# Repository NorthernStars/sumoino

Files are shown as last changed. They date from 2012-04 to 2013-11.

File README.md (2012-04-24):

Sumorobot library for Arduino
=============================

DESCRIPTION:
------------

* this library can be used to control 2 servo motors and 2 distance + 3 light sensors
* in the project you can also find the schematics for the arduino extensionboard

1) copy Sumorobot into your arduino libraries folder
2) restart Arduino and press Sketch > Import Library... > Sumorobot
3) check out the documentation "Sumorobot2012_documentation.pdf"
4) write some code xD (also the examples "Drive_EN", "Avoid_EN", "Opponent_EN" are available)

# download the library to the tmp and copy the library to the installed arduino
cd /var/tmp
git clone http://github.com/silps/sumoino.git
sudo cp -R sumoino/Sumorobot /usr/share/arduino/libraries

# if you don't have arduino 1.0 you need to do this additional step
# this will rename the example file formats into the old arduino format
sudo for i in `find /usr/share/arduino/libraries/Sumorobot/examples -name *.ino`;do mv $i ${i%.*}.pde;done

# after everything is done, open arduino and enjoy xD

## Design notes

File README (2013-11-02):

DESCRIPTION
===========

* this Arduino Sumorobot platform is developed for beginner programmers
* this Sumorobot uses 2 servo motors and 2 distance + 3 light sensors
* schematics folder contains the Arduino shield schematics
* frame folder containts the schematics for the frame
* documentation folder contains the documents for a Sumorobot workshop

INSTALLATION
============

Steps:
1) copy Sumorobot into your arduino libraries folder and restart arduino
2) check out the documentation https://github.com/silps/sumoino/raw/master/documentation/student.pdf
3) write some code xD (tip: see examples "Drive_EN", "Avoid_EN", "Opponent_EN")

Commands:
# this will install latest arduino and the Sumorobot library
# make sure that you will get arduino 1.0
sudo apt-get update && sudo apt-get install arduino && arduino
cd /var/tmp && git clone http://github.com/silps/sumoino.git
sudo cp -R sumoino/Sumorobot /usr/share/arduino/libraries

OTHER LINKS
===========
The gallery on google+ https://plus.google.com/photos/118227730440670321584/albums/5777266184562058609
The guide on instructables http://www.instructables.com/id/Arduino-Sumorobot/
The project poster https://www.sharelatex.com/project/52598a10e0deb8d1340053ea
The workshop slides https://docs.google.com/presentation/d/194JcJHCedPZimk41OGD4uriet_0rB0_b3bzhDWw4v1Q
The project report https://www.sharelatex.com/project/526d74ac7eea94a263004071

CREDITS ^-^
===========

* EIK Robotics Group
* NorthernStars Robotics Group
* Arduino developers
* Android developers
* Phonegap developers
* Blockly developers
* Amarino developers
* avrdude developers

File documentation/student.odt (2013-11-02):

# Sumoroboti programmeerimise juhend

### Liikumine

viivitus(1000); | Eelnevat käsku täidetakse 1000 millisekundit
stopp(); | Robot jääb seisma
edasi(); | Robot sõidab otse edasi
tagasi(); | Robot sõidab tagurpidi
paremale(); | Robot sõidab paremale
vasakule(); | Robot sõidab vasakule

### Edasijõudnutele

viivitus(SEKUND/2); | Eelnevat käsku täidetakse pool sekundit (Vihje: võib ka kasutada SEKUND/4 või teisi väärtusi)
paremMootor(suund, kiirus); Näide: paremMootor(EDASI, 75); | Roboti parema mootori kiiruse seadmine. Tuleb määrata suund ja kiirus (protsentides): suund > EDASI või TAGASI kiirus > 0 kuni 100
vasakMootor(suund, kiirus); Näide: vasakMootor(TAGASI, 50); | Roboti vasaku mootori kiiruse seadmine. Tuleb määrata suund ja kiirus (protsentides): suund > EDASI või TAGASI kiirus > 0 kuni 100

### Vastane

VASTANE_PAREM | Robot näeb vastast parema anduriga
VASTANE_VASAK | Robot näeb vastast vasaku anduriga
VASTANE_EES | Robot näeb vastast nii vasaku kui ka parema anduriga

### Joon

ALL_PAREM | Roboti all olev parempoolne joone andur
ALL_VASAK | Roboti all olev vasakpoolne joone andur
ALL_KESKMINE | Roboti all olev keskmine joone andur

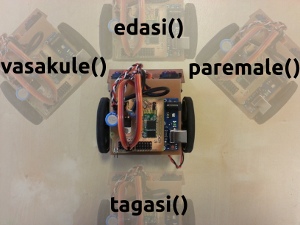
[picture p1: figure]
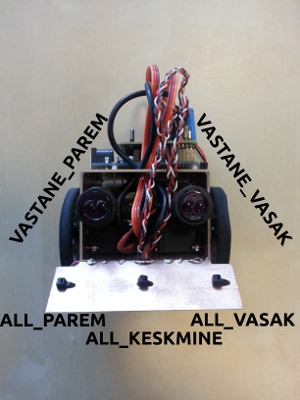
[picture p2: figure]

### Programmeerimine

Programmi struktuur

Sumoroboti programmeerimiseks kasutame järgnevat Arduino programmi struktuuri:

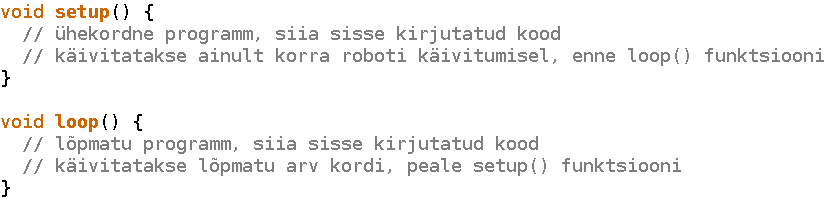
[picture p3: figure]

Vajalike teekide lisamine

Sumoroboti juhtimiseks lisa Sumoroboti ja Servo teegid, mis sisaldavad vajalikke funktsioone, et sumorobotit juhtida. Selleks vajuta arduino keskkonnas järgnevaid nuppe menüüst:
1) 2) 3)

4) 5) 6)

Programmi kompileerimine ja laadimine

Kui programm on valmis, siis vajuta nuppu menüüst, et see kompileerida. Veendu, et näed vasakul all nurgas teadet. Viimaks vajuta, et programm Sumorobotisse laadida.

Juhul, kui Arduino leidis programmis vigu, annab ta veateate . Sellel juhul kontrolli oma kood üle ning raskuste korral kutsu appi juhendaja.

Näiteprogrammid

Kahtluse korral saab ka proovida näiteprogramme, need leiab järgnevate menüü nupuvajutustega:

1) 2) 3)

Sealt tuleb valida sobiv näide EE lõpuga.

Lõbusat programmeerimist!

# Sumorobot programming guide

### Movement

delay(1000); | Previous command is carried out for 1000 milliseconds
stop(); | The robot stops
forward(); | The robot moves forward
backward(); | The robot moves backwards
right(); | The robot moves right
left(); | The robot moves left

### Advanced

delay(SECOND/2); | Previous command is carried out for half a second (Tip: SECOND/4 or other values may also be used)
rightMotor(direction, speed); Example: rightMotor(FORWARD, 75); | To set the speed of the right motor. Specify the direction and speed (in percentage): direction > FORWARD or BACKWARD speed > 0 to 100
leftMotor(direction, speed); Example: leftMotor(BACKWARD, 50); | To set the speed of the left motor. Specify the direction and speed (in percentage): direction > FORWARD or BACKWARD speed > 0 to 100

### Opponent

OPPONENT_RIGHT | The robot sees the opponent with the right sensor
OPPONENT_LEFT | The robot sees the opponent with the left sensor
OPPONENT_FRONT | The robot sees the opponent with both the left and right sensor

### Line

BOTTOM_RIGHT | The right line sensor under the robot
BOTTOM_LEFT | The left line sensor under the robot
BOTTOM_MIDDLE | The middle line sensor under the robot

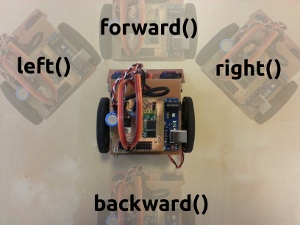
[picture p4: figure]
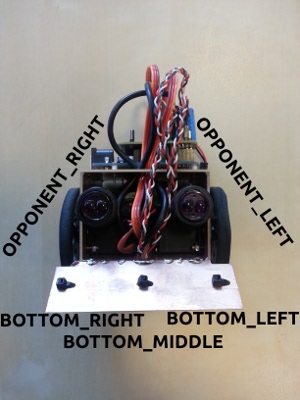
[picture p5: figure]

### Programming

Program structure

The following Arduino program structure is used to program the Sumorobot:

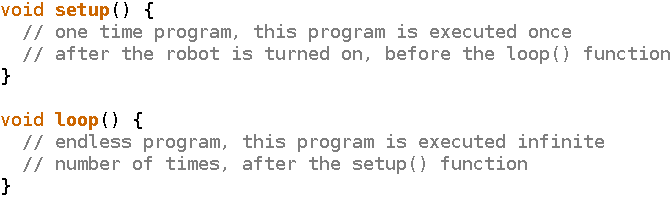
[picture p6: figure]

Adding necessary libraries

For controlling the Sumorobot we need to add the Sumorobot and Servo library, which contain necessary functions to control the Sumorobot. For that click on the following menu buttons:
1) 2) 3)

4) 5) 6)

Compiling and uploading

When the program is ready, then push from the menu, to compile the program. Be sure that you see the message on the bottom left corner. Finally press and the program will be uploaded.

In case Arduino found bugs in your program, you will see the message . In this case recheck your program and if in doubt ask the supervisor for help.

Example programs

There are also example programs available, if in doubt. They can be found by pressing the following menu buttons:

1) 2) 3)

From there you need to choose the examples ending with EN.

Happy programming!

# Anleitung für Sumorobot Programmierung

### Bewegung

warte(1000); | Letzter Befehl wird 1000 millisekunden ausgeführt
stop(); | Der Roboter hält an
vorwaerts(); | Der Roboter fährt vorwaerts
rueckwaerts(); | Der Roboter fährt rückwaerts
rechts(); | Der Roboter fährt nach rechts
links(); | Der Roboter fährt nach links

### Vortgeschritten

warte(SEKUNDE/2); | Letzter Befehl wird halbe Sekunde ausgeführt (Tip: SEKUNDE/4 oder auch andere Werte)
rechterMotor(richtung, geschwind.); Beispiel: rechterMotor(VORWAERTS, 75); | Um die Geschwindigkeit von dem linken Motor zu bestimmen. Gib die Richtung und Geschwindigkeit: richtung > VORWAERTS oder RUCKWERTS geschwindigkeit > 0 bis 100 (im Protzent)
linkerMotor(richtung, geschwind.); Beispiel: linkerMotor(RUECKWAERTS, 50); | Um die Geschwindigkeit von dem rechten Motor zu bestimmen. Gib die Richtung und Geschwindigkeit richtung > VORWAERTS oder RUECKWAERTS geschwindigkeit > 0 bis 100 (im Protzent)

### Gegner

GEGNER_RECHTS | Der rechter Gegner-Sensor auf dem Roboter (Gegner rechts)
GEGNER_LINKS | Der linke Gegner-Sensor auf dem Roboter (Gegner links)
GEGNER_VORNE | Beide Gegner-Sensoren auf dem Roboter (Gegner vorne)

### Linie

UNTEN_RECHTS | Der rechte Linien-Sensor (Linie rechts)
UNTEN_LINKS | Der linke Linien-Sensor (Linie links)
UNTEN_MITTE | Der mittlere Linien-Sensor (Linie vorne)

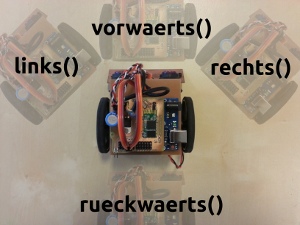
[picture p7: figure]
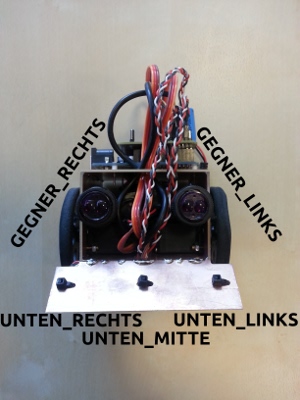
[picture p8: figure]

### Programmierung

Struktur vom Programm

Die folgende Arduino Programmstruktur wird benutzt um den Sumoroboter zu programmieren:

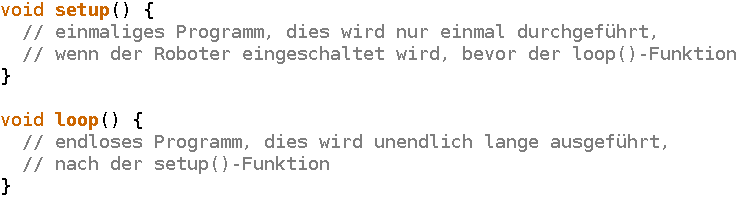
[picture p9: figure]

Benötigte Bibliotheken

Für die Kontrolle von dem Sumoroboter brauchen wir die Sumorobot und Servo Bibliothek. Am Menü wähle folgendes:
1) 2) 3)

4) 5) 6)

Kompilierung und Upload

Wenn der Programm fertig ist, dann drück , um es to kompilieren. Sei sicher, dass Du die Nachricht siehst. Am ende drücke um den Program zu uploaden.

Im Falle das Arduino Bugs gefunden hat wirst du die Nachricht sehen. Im diesem Falle überprüfe nochmal dein Porgramm und im Zweifel frage deinen Betruer.

Beispiel Programme

Im Zweifel gibt es auch Beispiel Programme. Die kann man im Menü folgender weise finden:

1) 2) 3)

Darunter muss man die Beispiele mit dem Ende DE auswählen.

Viel Spaß beim programmieren!

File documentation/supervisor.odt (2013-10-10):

# Sumoroboti töötoa ettevalmistamine

Enne igat koolitust tuleb veenduda, et:

1. Arvutitel on Arduino ja Sumoroboti teek installeeritud:
- lae alla ja installeeri Arduino http://www.arduino.cc/download
- lae alla ja installeeri Sumoroboti teek https://github.com/silps/sumoino
2. Sumoroboti akud oleks täidetud:
- multimeetriga mõõda ligikaudu 7,4V aku kohta
3. Sumorobotil töötavad näiteprogrammid:
- lae Sumorobotisse näiteprogramm

Juhul, kui midagi ei tööta:

Vaata üle kas juhtmed on õigesti ühendatud:

- parem mootor nr 6 ja vasak nr 5 pistikus
- vastase parem andur nr 0 ja vasak nr 1 pistikus
- joone parem andur nr 2, keskmine nr 3 ja vasak nr 4 pistikus

Kasuta teeki sisse ehitatud “test” funktsioone:

- testOpponent(); ( nähes vastast, ründab )
- testLine(); ( sõidab otse ja väldib joont )
- testSensors(); ( väljastab kõik anduri väärtused konsooli )

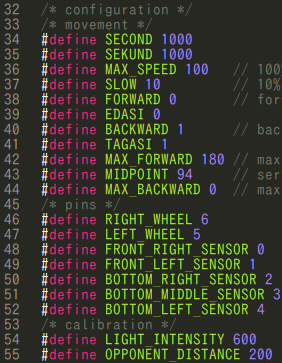
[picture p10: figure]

Kalibreeri võimalike väärtusi “Sumo.h” failis:

- valguse intensiivsust jooneanduril ( LIGHT_INTENSITY )
- vastase nägemise kaugust ( OPPONENT_DISTANCE )
- servo mootorite keskpunkti, ehk stopp punkti ( MIDPOINT )

# Sumorobot Workshop preparation

Before the workshop, be sure that:

1. The computers have Arduino and the Sumorobot library installed:
- download and install Arduino http://www.arduino.cc/download
- download and install the Sumoroboti library https://github.com/silps/sumoino
2. The batteries of the Sumorobots are charged:
- measure approximately 7,4V per battery
3. The example programs are working on the Sumorobots:
- upload the examples to the Sumorobots

In case something doesn't work:

Check that all cables are connected correctly:

- right motor nr 6 and left nr 5 pin
- opponent right sensor nr 0 and left nr 1 pin
- line right sensor nr 2, middle nr 3 and left nr 4 pin

Use the built-in “test” functions:

- testOpponent(); ( attacks the opponent, when in range )
- testLine(); ( drives forward and avoids line )
- testSensors(); ( prints out all the sensor values to the console )

Calibrate possible values in “Sumo.h” file:

- the light intensity of the line sensor ( LIGHT_INTENSITY )
- the opponent detection distance ( OPPONENT_DISTANCE )
- servo motor midpoint or stopping point ( MIDPOINT )

# Sumoroboter Workshop Vorbereitung

Vor dem Workshop, sei sicher dass:

1. Die Computer haben Arduino und die Sumoroboter Bibliothek installiert:
- downloade und installiere Arduino http://www.arduino.cc/download
- downloade und installiere die Bibliothek https://github.com/silps/sumoino
2. Die Batterien von den Sumorobotern sind voll:
- messe ungefähr 7,4V pro Batterie
3. Die Beispiel Programme funktionieren auf den Sumorobotern:
- uploade die Beispiele auf die Sumoroboter

Im Falle das was nicht funktsioniert:

Siehe ob alle Kabel richting verbunden sind:

- rechter Motor nr 6 und linker nr 5 pin
- rechter Gegner-Sensor nr 0 und linker nr 1 pin
- rechter Linien-Sensor nr 2, mitlerer nr 3 und linker nr 4 pin

Benutze die built-in “test” Funktione:

- testOpponent(); ( greift den Gegner an, wenn im Umfeld )
- testLine(); ( fährt vorwaerts und vermeidet die Linie )
- testSensors(); ( schick alle Sensor Daten in die Konsole )

Kalibriere mögliche Werte in File “Sumo.h”:

- die Intensität vom Lichtsensor ( LIGHT_INTENSITY )
- die Gegnererkennungs-Distanz ( OPPONENT_DISTANCE )
- der Mittelwert oder Stoppwert vom Servo ( MIDPOINT )

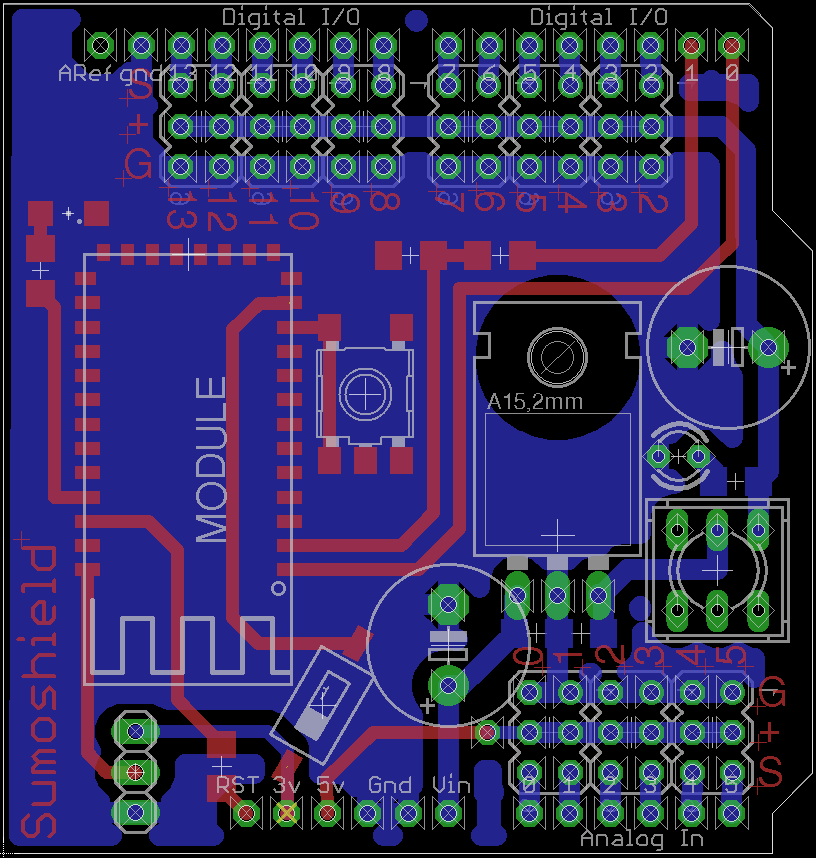
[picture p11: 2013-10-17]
schematics/board.png

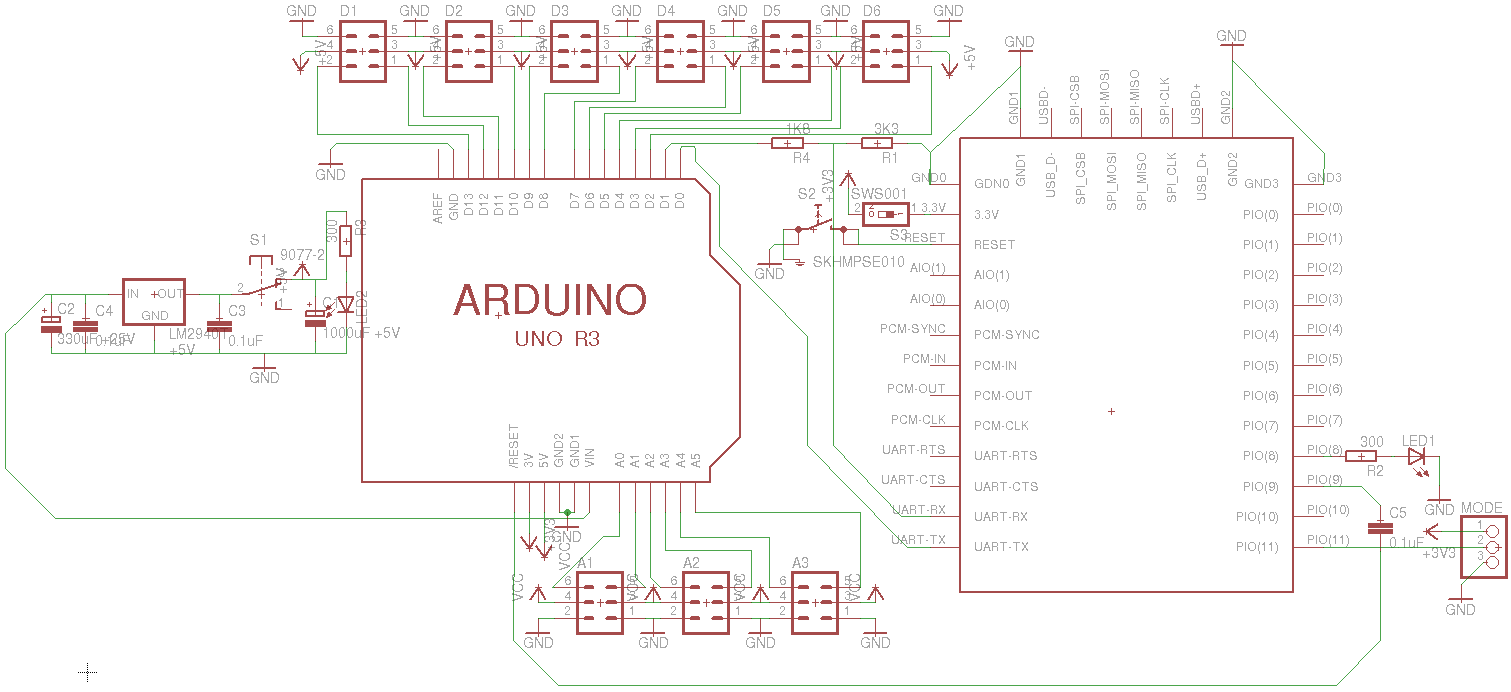
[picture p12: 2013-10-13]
schematics/schema.png

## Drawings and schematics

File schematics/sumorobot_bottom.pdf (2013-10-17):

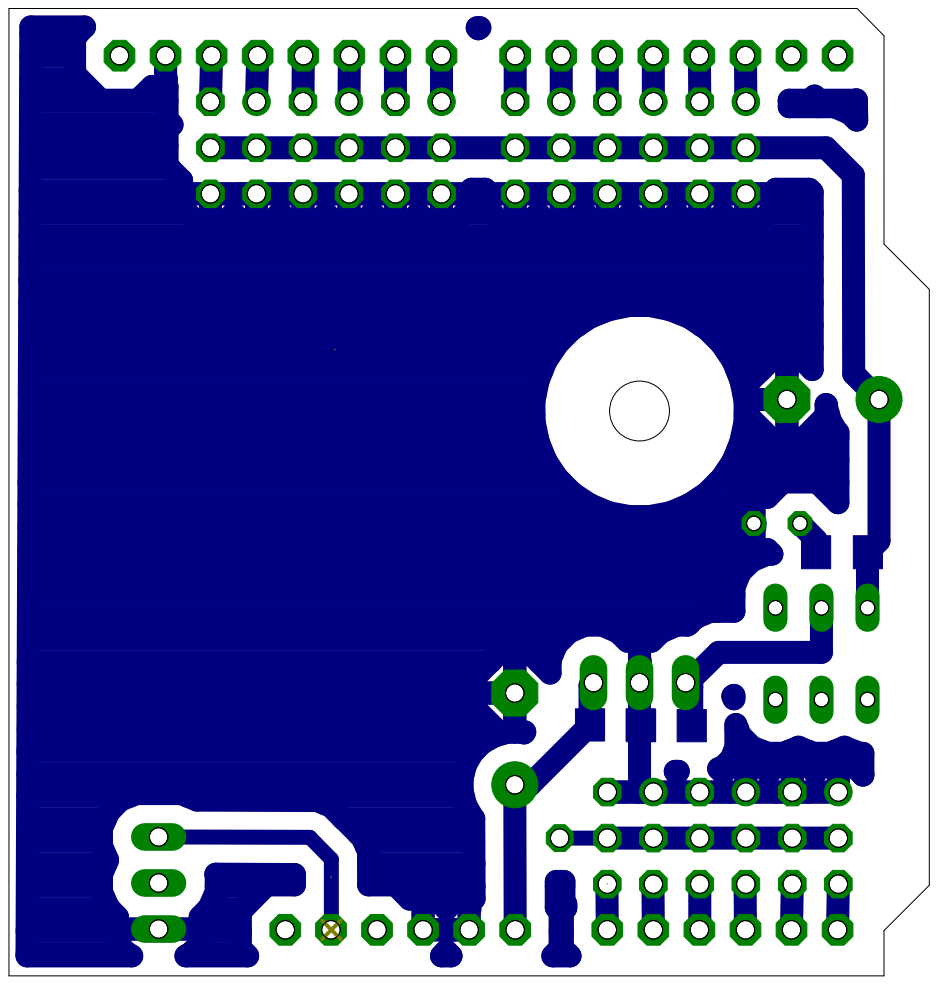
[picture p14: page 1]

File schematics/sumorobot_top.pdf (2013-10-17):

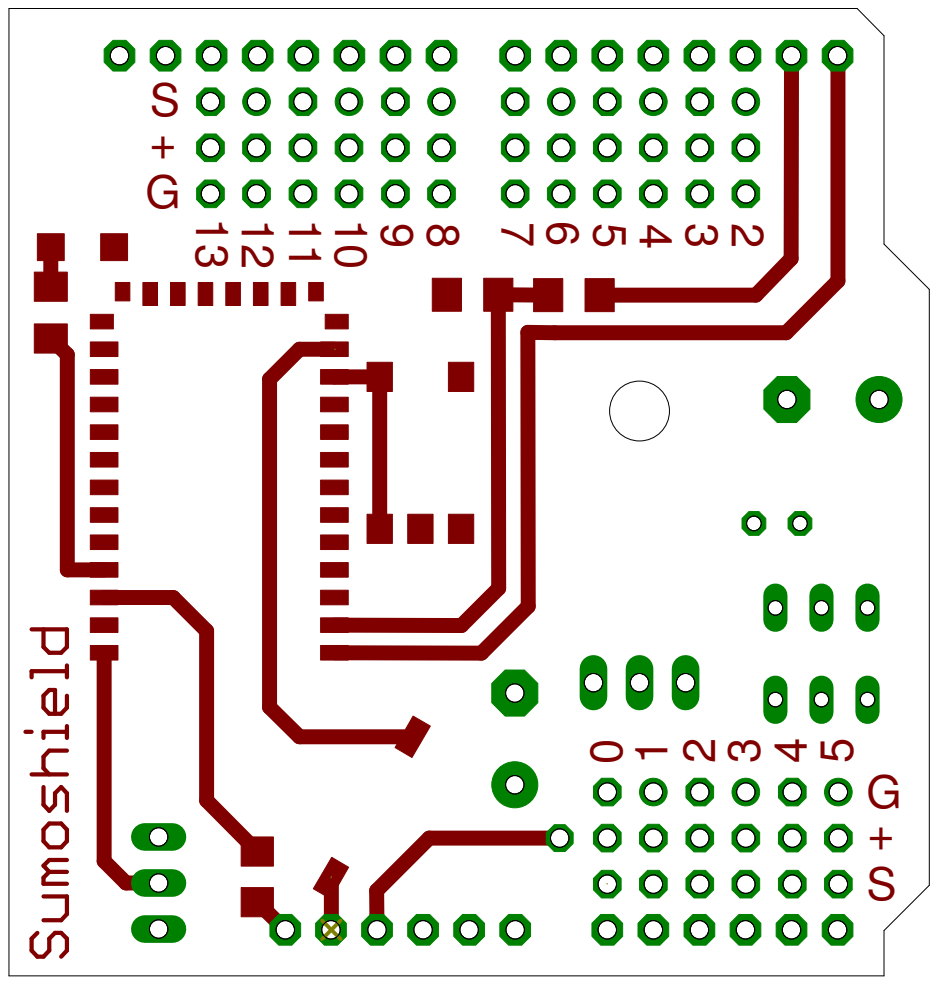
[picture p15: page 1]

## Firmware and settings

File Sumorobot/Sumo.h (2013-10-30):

/*
Sumo.h - Sumorobot library for Arduino

Author (C) 2012 The Estonian Information Technology College Robotics Club
Author (C) 2012 Silver Kuusik <silver.kuusik@gmail.com>

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
You should have received a copy of the GNU General Public License
along with this program; if not, write to the Free Software
Foundation, Inc., 51 Franklin Street, Fifth Floor, Boston, MA  02110-1301, USA.
*/

#ifndef Sumo_h
#define Sumo_h

#include "../Servo/Servo.h"

/* for C style compilation */
extern "C" {
  #include "stdlib.h"
}

/* configuration */
/* movement */
#define MAX_FORWARD 180 // max forward speed
#define MIDPOINT 90     // servo midpoint, brake
#define MAX_BACKWARD 0  // max backward speed
/* pins */
#define RIGHT_WHEEL 6
#define LEFT_WHEEL 5
#define FRONT_RIGHT_SENSOR 0
#define FRONT_LEFT_SENSOR 1
#define BOTTOM_RIGHT_SENSOR 2
#define BOTTOM_MIDDLE_SENSOR 3
#define BOTTOM_LEFT_SENSOR 4
/* calibration */
#define LIGHT_INTENSITY 600
#define OPPONENT_DISTANCE 200
/* for further calibration */
#define OPPONENT_DISTANCE_LEFT OPPONENT_DISTANCE
#define OPPONENT_DISTANCE_RIGHT OPPONENT_DISTANCE
#define LIGHT_INTENSITY_RIGHT LIGHT_INTENSITY
#define LIGHT_INTENSITY_LEFT LIGHT_INTENSITY
#define LIGHT_INTENSITY_MIDDLE LIGHT_INTENSITY


/* motors */
static Servo rightWheel;
static Servo leftWheel;

/* english version */

/* constants */
#define SECOND 1000
#define MAX_SPEED 100   // 100% of speed
#define SLOW 10         // 10% of speed
#define FORWARD 0       // forward direction
#define BACKWARD 1      // backward direction

/* initialization */
void start();
/* movement */
int getSpeed(uint8_t, uint8_t, uint8_t);
void stop();
void forward();
void backward();
void right();
void left();
int rightMotor(uint8_t, uint8_t);
int leftMotor(uint8_t, uint8_t);

/* sensors */
#define READ_OPPONENT(analog, distance) (analogRead(analog) > distance)
#define READ_BOTTOM(analog, distance) (analogRead(analog) < distance)
/* opponent */
#define OPPONENT_RIGHT READ_OPPONENT(FRONT_RIGHT_SENSOR, OPPONENT_DISTANCE_RIGHT)
#define OPPONENT_LEFT READ_OPPONENT(FRONT_LEFT_SENSOR, OPPONENT_DISTANCE_LEFT)
#define OPPONENT_FRONT (OPPONENT_LEFT && OPPONENT_RIGHT)
/* field */
#define BOTTOM_RIGHT READ_BOTTOM(BOTTOM_RIGHT_SENSOR, LIGHT_INTENSITY_RIGHT)
#define BOTTOM_LEFT READ_BOTTOM(BOTTOM_LEFT_SENSOR, LIGHT_INTENSITY_LEFT)
#define BOTTOM_MIDDLE READ_BOTTOM(BOTTOM_MIDDLE_SENSOR, LIGHT_INTENSITY_MIDDLE)

/* for testing */
#define followLine() \
{ \
    if (BOTTOM_RIGHT) { right(); } \
		else if (BOTTOM_LEFT) { left(); } \
    else forward(); \
}
#define testOpponent() \
{ \
    if (OPPONENT_FRONT) forward(); \
    else if (OPPONENT_LEFT) left(); \
    else if (OPPONENT_RIGHT) right(); \
    else stop(); \
}
#define testLine() \
{ \
    if (BOTTOM_RIGHT) { left(); } \
		else if (BOTTOM_LEFT) { right(); } \
    else forward(); \
}
#define testSensors() \
{ \
    Serial.print( "right: " ); \
    Serial.print( analogRead(FRONT_RIGHT_SENSOR) ); \
    Serial.print( " left: " ); \
    Serial.println( analogRead(FRONT_LEFT_SENSOR) ); \
    Serial.print( " line_left: "); \
    Serial.print( analogRead(BOTTOM_LEFT_SENSOR) ); \
    Serial.print( " line_middle: "); \
    Serial.print( analogRead(BOTTOM_MIDDLE_SENSOR) ); \
    Serial.print( " line_right: "); \
    Serial.println( analogRead(BOTTOM_RIGHT_SENSOR) ); \
    Serial.println(); \
}
/* end of english version */

/* estonian version */

/* constants */
#define SECOND 1000
#define MAX_KIIRUS 100 	// 100% of speed
#define AEGLANE 10      // 10% of speed
#define EDASI 0       	// forward direction
#define TAGASI 1      	// backward direction

/* sensors */
/* opponent */
#define VASTANE_PAREM OPPONENT_RIGHT
#define VASTANE_VASAK OPPONENT_LEFT
#define VASTANE_EES OPPONENT_FRONT
/* field */
#define ALL_PAREM BOTTOM_RIGHT
#define ALL_VASAK BOTTOM_LEFT
#define ALL_KESKMINE BOTTOM_MIDDLE

/* movement */
#define viivitus(time) (delay(time))
#define stopp() (stop())
#define edasi() (forward())
#define tagasi() (backward())
#define paremale() (right())
#define vasakule() (left())
#define paremMootor(dir, speed_percentage) (rightMotor(dir, speed_percentage))
#define vasakMootor(dir, speed_percentage) (leftMotor(dir, speed_percentage))

/* end of estonian version */

/* german version */

/* constants */
#define SEKUNDE 1000
#define MAX_TEMPO 100 	// 100% of speed
#define LANGSAM 10 			// 10% of speed
#define VORWAERTS 0 		// forward direction
#define RUECKWAERTS 1 	// backward direction

/* sensors */
/* opponent */
#define GEGNER_RECHTS OPPONENT_RIGHT
#define GEGNER_LINKS OPPONENT_LEFT
#define GEGNER_VORNE OPPONENT_FRONT
/* field */
#define UNTEN_RECHTS BOTTOM_RIGHT
#define UNTEN_LINKS BOTTOM_LEFT
#define UNTEN_MITTE BOTTOM_MIDDLE

/* movement */
#define warte(time) (delay(time))
#define stop() (stop())
#define vorwaerts() (forward())
#define rueckwaerts() (backward())
#define rechts() (right())
#define links() (left())
#define rechterMotor(dir, speed_percentage) (rightMotor(dir, speed_percentage))
#define linkerMotor(dir, speed_percentage) (leftMotor(dir, speed_percentage))

/* end of german version */

#endif

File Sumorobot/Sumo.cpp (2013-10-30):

/*
Sumo.cpp - Sumorobot library for Arduino

Author (C) 2012 The Estonian Information Technology College Robotics Club
Author (C) 2012 Silver Kuusik <silver.kuusik@gmail.com>

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
You should have received a copy of the GNU General Public License
along with this program; if not, write to the Free Software
Foundation, Inc., 51 Franklin Street, Fifth Floor, Boston, MA  02110-1301, USA.
*/

#include "Sumo.h"

/* init function */
void start()
{
  /* initialize the wheels */
  rightWheel.attach(RIGHT_WHEEL);
  leftWheel.attach(LEFT_WHEEL);
}

/* function to calculate the the motor speed given the wheel, directory and speed in precentage
 @param wheel ( RIGHT_WHEEL or LEFT_WHEEL )
 @param dir ( BACKWARD or FORWARD )
 @param speed_percentage ( 0 to 100 )
 @return errorcode
 */
int getSpeed(uint8_t wheel, uint8_t dir, uint8_t speed_percentage)
{
  /* if precentage out of rage, return error */
  if ( speed_percentage < 0 || speed_percentage > 100 ) return -3;
  /* if the wheel is unknown, return error */
  if ( wheel != RIGHT_WHEEL && wheel != LEFT_WHEEL ) return -2;
  /* if the we operate with the right wheen, we need to turn the direction, because the motor is flipped */
  if ( wheel == RIGHT_WHEEL ) dir = !dir;
  if (dir == FORWARD) {
    /* the forward speed is MIDPOINT - MAX_FORWARD, for speed calculation we need to move the 0 point */
    return ((speed_percentage / 100.0) * (MAX_FORWARD - MIDPOINT)) + MIDPOINT;
  } else if (dir == BACKWARD) {
    /* the backward speed is MIDPOINT - MAX_BACKWARD, for speed calculation we need to revert the result */
    return abs(((speed_percentage / 100.0) * MIDPOINT) - MIDPOINT);
  } else {
    /* if the direction was not valid return error */
    return -1;
  }
}

/* to break  */
void stop()
{
  rightWheel.write(MIDPOINT);
  leftWheel.write(MIDPOINT);
}

/*  */
void forward()
{
  rightWheel.write(getSpeed(RIGHT_WHEEL, FORWARD, MAX_SPEED));
  leftWheel.write(getSpeed(LEFT_WHEEL, FORWARD, MAX_SPEED));
}

void backward()
{
  rightWheel.write(getSpeed(RIGHT_WHEEL, BACKWARD, MAX_SPEED));
  leftWheel.write(getSpeed(LEFT_WHEEL, BACKWARD, MAX_SPEED));
}

void right()
{
  rightWheel.write(getSpeed(RIGHT_WHEEL, FORWARD, MAX_SPEED / 25));
  leftWheel.write(getSpeed(LEFT_WHEEL, FORWARD, MAX_SPEED));
}

void left()
{
  rightWheel.write(getSpeed(RIGHT_WHEEL, FORWARD, MAX_SPEED));
  leftWheel.write(getSpeed(LEFT_WHEEL, FORWARD, MAX_SPEED / 25));
}

/* function to move right wheel forward or backward with a specific speed
 @param dir ( FORWARD or BACKWARD )
 @param speed_percentage ( 0 to 100 )
 */
int rightMotor(uint8_t dir, uint8_t speed_percentage)
{
  int speed = getSpeed(RIGHT_WHEEL, dir, speed_percentage);
  /* if parameters out of range, return error */
  if ( speed < 0 ) return speed;
  /* otherwise set the speed for the wheel */
  rightWheel.write(speed);
}

/* function to move left wheel forward or backward with a specific speed
 @param dir ( FORWARD or BACKWARD )
 @param speed_percentage ( 0 to 100 )
 */
int leftMotor(uint8_t dir, uint8_t speed_percentage)
{
  int speed = getSpeed(LEFT_WHEEL, dir, speed_percentage);
  /* if parameters out of range, return error */
  if ( speed < 0 ) return speed;
  /* otherwise set the speed for the wheel */
  leftWheel.write(speed);
}

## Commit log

2011-10-29 added sumorobot library, sumoshield schematics and sumorobot body schematics
    [sumo_body.dxf, sumorobot.brd, sumorobot.sch]
2011-10-29 added sumorobot library, sumoshield schematics and sumorobot body schematics
    mend
2012-04-22 removed obsolete body schematics
    [sumo_body.dxf]
2012-04-22 renamed folders
    [sumorobot.brd, sumorobot.sch]
2012-04-24 added direction parameter for wheel controlling
2012-07-26 updated student printouts
    [sumorobot.brd, sumorobot.sch]
2012-08-18 Update Sumorobot/Sumo.h
    fixed type for estonian version
    [Sumo.h]
2012-08-18 Update Sumorobot/examples/Opponent_EE/Opponent_EE.ino
    fixed type for sensor macros
    [Opponent_EE.ino]
2012-08-18 Update Sumorobot/Sumo.h
    fixed type testSensor to testSensors
    [Sumo.h]
2012-10-11 defined estonian parameters for advanced motor control (forward and backward)
2013-01-29 updated schematics and frame
    [sumoino.dxf, sumorobot.brd, sumorobot.sch]
2013-10-10 updated library names and Arduino layout
2013-10-10 updated frame
    [sumoino.dxf]
2013-10-10 deleted obsolete frame and added new
    [frame.brd, sumoino.dxf]
2013-10-10 updated schematics and board
    [sumorobot.brd, sumorobot.sch]
2013-10-12 updated keywords and added dip switch for bluetooth
    [sumorobot.brd, sumorobot.sch]
2013-10-13 updated schematics and board illustrations
2013-10-13 updated frame and schematics board
    [frame.brd, sumorobot.brd]
2013-10-13 added frame illustration
2013-10-17 updated shield schematics
    [sumorobot.brd]

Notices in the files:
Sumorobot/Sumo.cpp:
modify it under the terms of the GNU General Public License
